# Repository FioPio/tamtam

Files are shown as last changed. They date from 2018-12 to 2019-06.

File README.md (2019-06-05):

# tamtam
!!!!!!!!!!!!!!!!!!!!!!!!!!!!!!!UNDER CONSTRUCTION!!!!!!!!!!!!!!!!!!!!!!!!!!!!!!
This repo holds Tamtam (an small low-cost humanoid).
It will contain all the documentation needed to build that litte
robot.
It has 19 DOF, those will be mg90s. I expect to finish it very
son. Since now I have done all of the hardware, the electronics are 
working fine and I've already computed the inverse kinematics.

I am working on the code,and there will be also a document explaining
all the details , since this is my degree project.

the robot is 223.25 mm hight

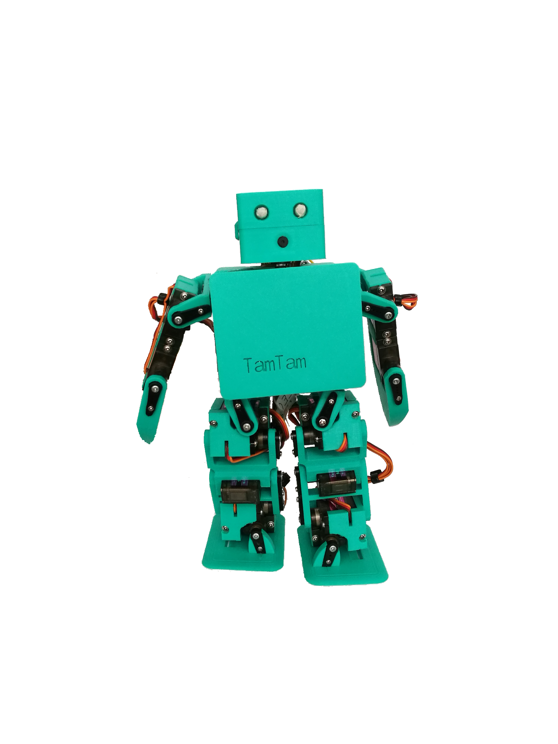
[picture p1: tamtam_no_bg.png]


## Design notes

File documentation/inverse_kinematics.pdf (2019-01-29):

INVERSE KINEMATICS:

That’s a Tamtam leg schema in the zy and zx planes :

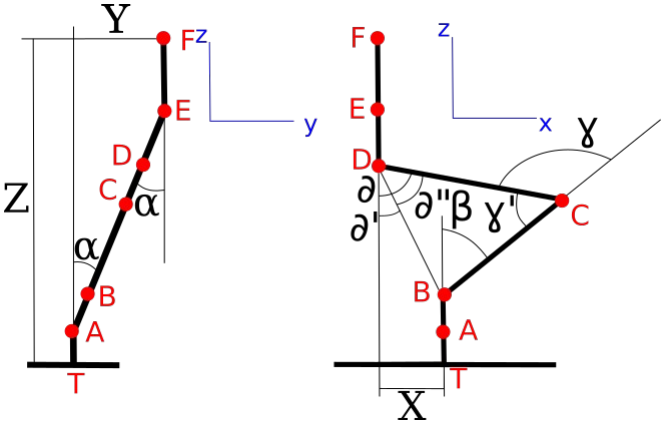
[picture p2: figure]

Where T is refered from F and has the components ( X , Y, Z ), so first we may compute the α angle:

α=tg⁻¹
(

Y
Z−TA−EF

)

Now we can compute the distance between B and D using pitagoras:

BD=√ X
2
+(Y −ABsinα−DE sinα)

2
+( Z− ABcosα−DE cosα−TA−EF )

2

So now we have a triangle which we know all the dimensions but the angles: aplying the law of cosinus we may obtain γ’ angle:

γ '=cos⁻¹
(

BC²

+CD²− BD²

### 2 BC CD

)

and since γ = 180 -γ’ :

γ=180−cos⁻¹
(

BC²

+CD²−BD²

### 2 BC CD

)

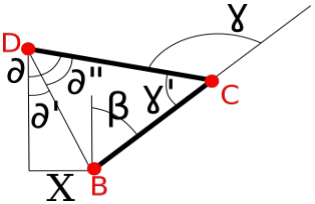
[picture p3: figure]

we also may compute ð’: δ '=sin⁻¹ (

X
BD

) and ð”: δ ''=cos⁻¹
(

CD²

+ BD²−BC²
2CD BD

)

And since ð = ð’ + ð “:

δ=sin⁻¹
(

X
BD

)+cos⁻¹
(

CD²

+ BD²− BC²
2CD BD

)

And to finish, using the fact that adding all the intern angles of a triangle you get 180 degrees:

β=180−δ−(180−γ)=γ−δ

Now we need to add the rotation component for the leg, I’ll use a rotation matrix in Z axis:

so we obtain: x,y,z,ε → X,Y,Z:

to do so:
X = x cos ε + y sin ε
Y = y cos ε – x sin ε
Z= z
where ε is the F rotation angle.

by FioPio (Ferriol Pey Comas)

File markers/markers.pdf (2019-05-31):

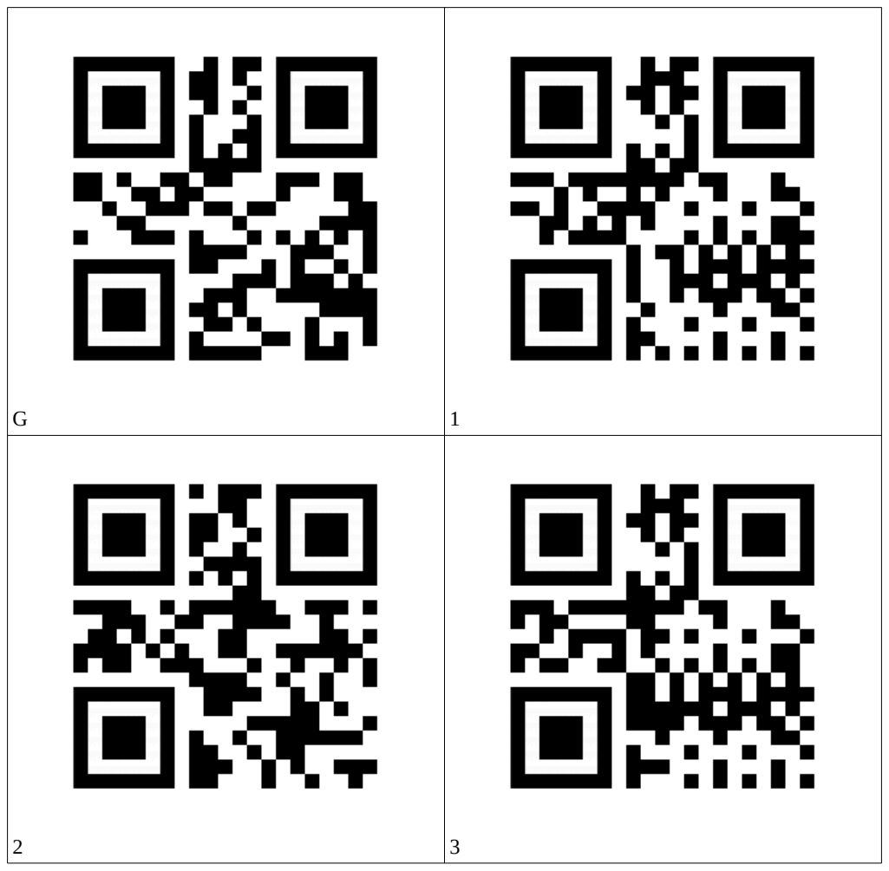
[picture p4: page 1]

G

1

2

3

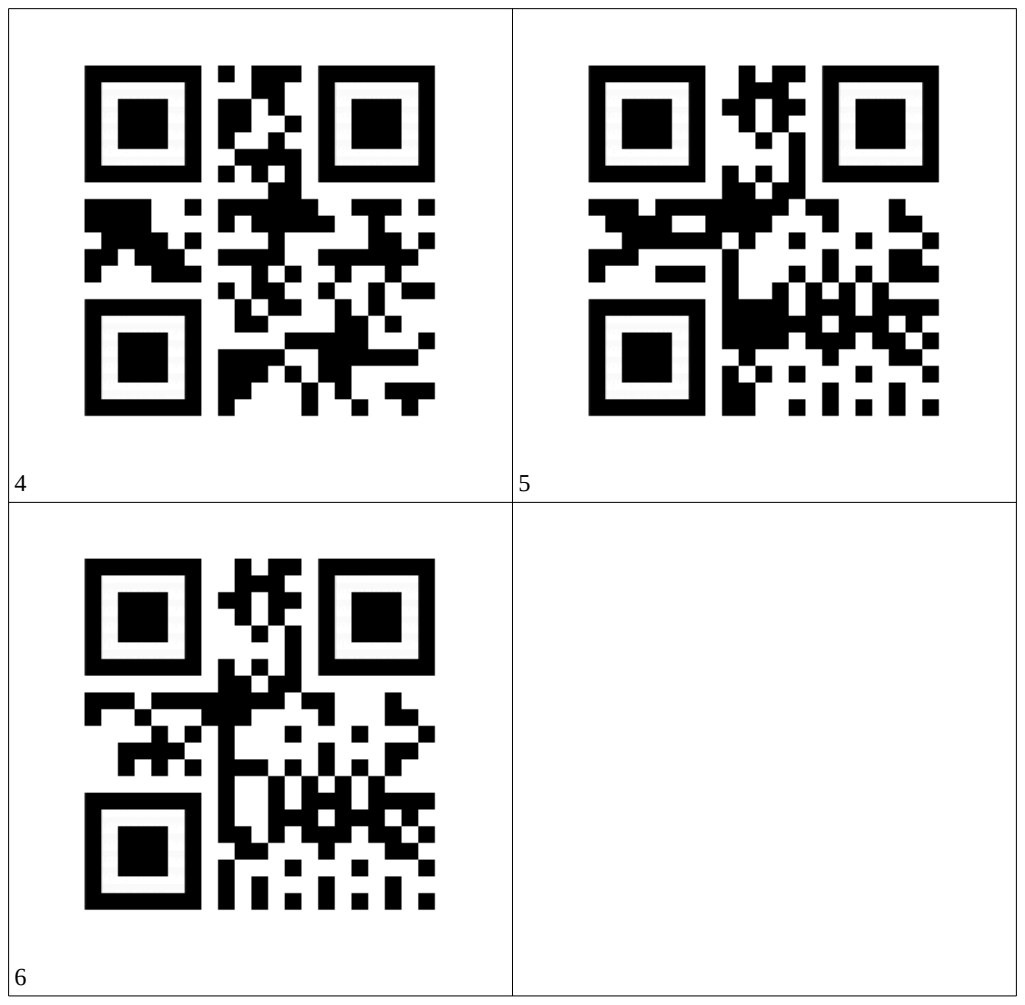
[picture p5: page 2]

4

5

6

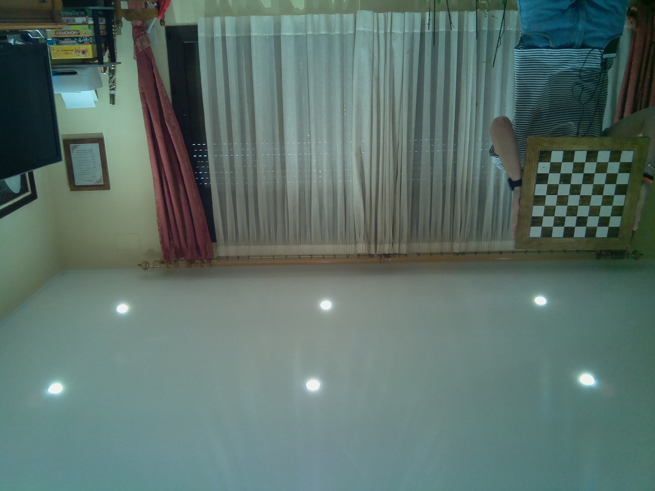
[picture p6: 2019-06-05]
code/rpi/photo_cal/photos/f18.jpg

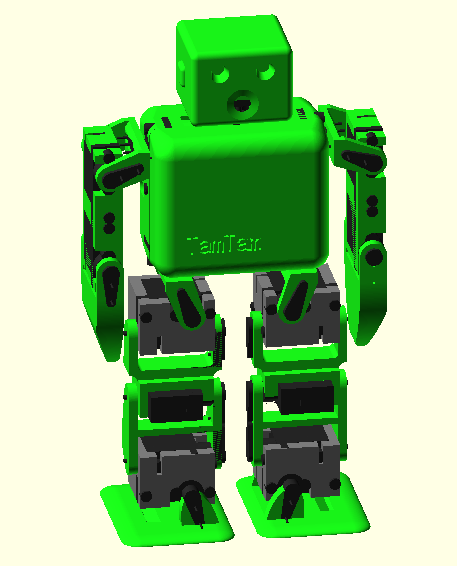
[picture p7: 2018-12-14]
TamTam_view1.png

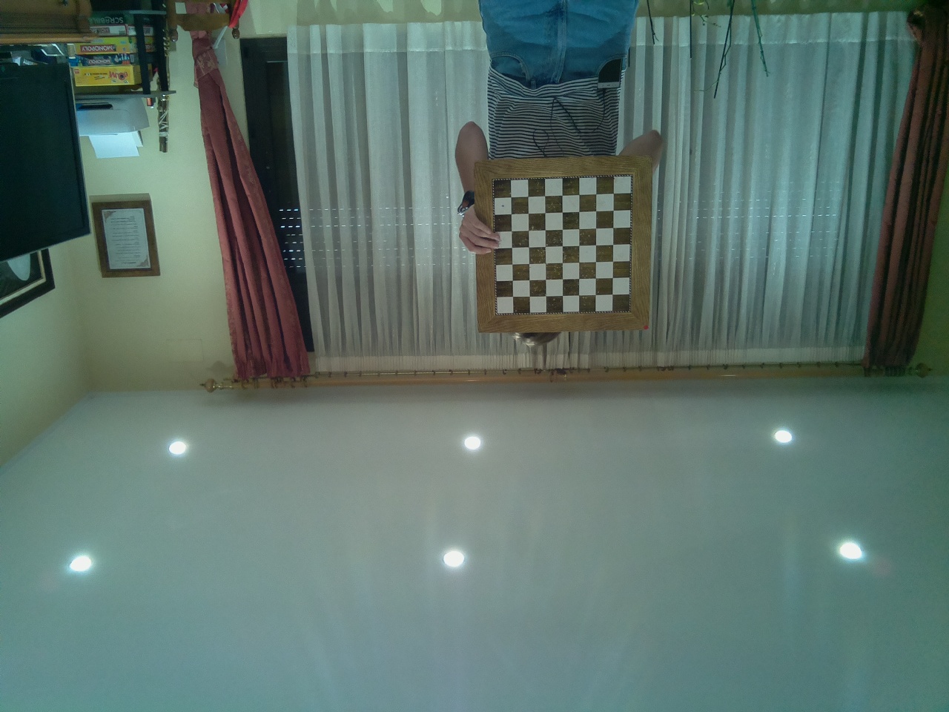
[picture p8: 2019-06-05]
code/rpi/photo_cal/photos/f10.jpg

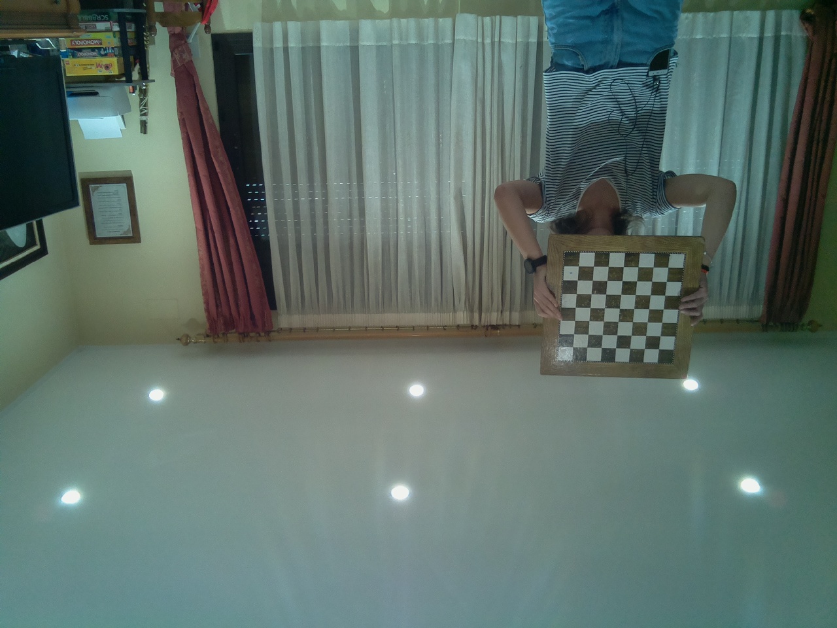
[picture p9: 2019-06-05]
code/rpi/photo_cal/photos/f13.jpg

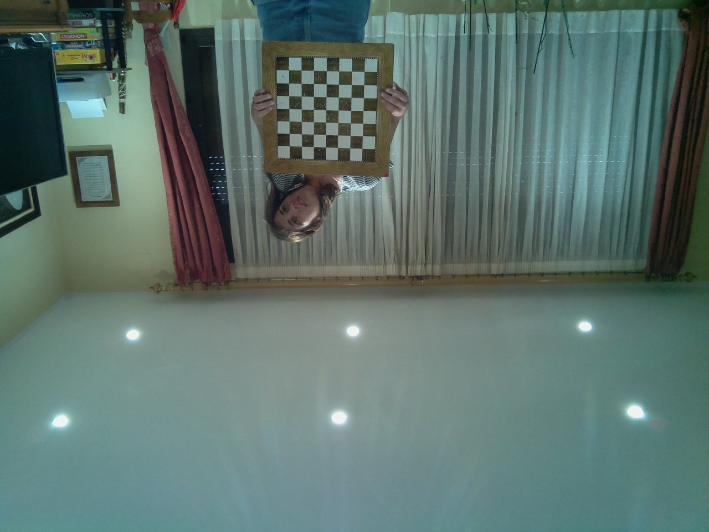
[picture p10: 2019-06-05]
code/rpi/photo_cal/photos/f7.jpg

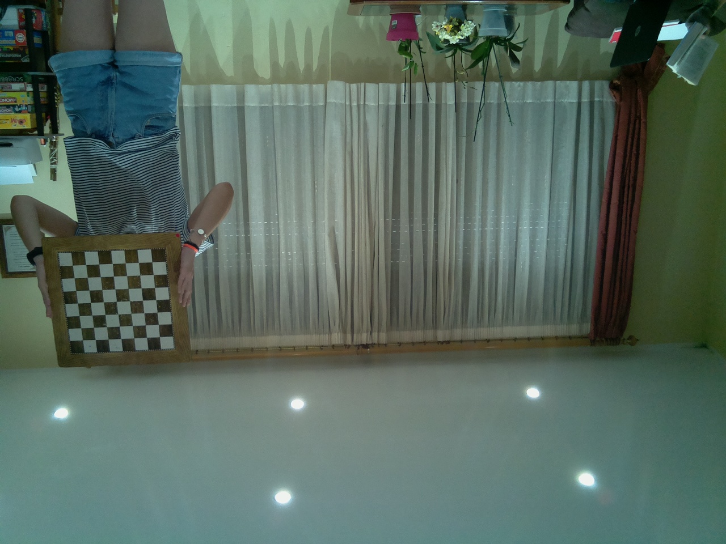
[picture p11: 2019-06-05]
code/rpi/photo_cal/photos/f2.jpg

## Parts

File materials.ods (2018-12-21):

component | units | aprox priece (€/u) | total priece | 3D piece | density (%) | p. time | units | total printing time | 12:25:00 | hours
MG90S | 19 | 1,822 | 34,618 | two_servo_holder | 10 | 01:00:00 | 2 | 03:50:00
Conic M2x6 | 14 | 0,0334 | 0,4676 | two_servo_holder (mirrored) | 10 | 01:00:00 | 2
ATMega328P-AU | 1 | 1,164 | 1,164 | right_foot | 10 | 01:35:00 | 1 | 02:40:00
SD20 | 1 | 11,5 | 11,5 | right_foot (mirrored) [for left foot] | 10 | 01:35:00 | 1
board | 1 | 0,858 | 0,858 | lower_leg_right | 10 | 00:45:00 | 1 | 01:15:00
100nF Capacitor | 1 | 0,00578 | 0,00578 | lower_leg_right (mirrored) [for left] | 10 | 00:45:00 | 1
47uF Capacitor | 1 |  | 0 | upper_leg_right | 10 | 00:56:00 | 1 | 01:15:00
22pF Capacitor | 2 | 0,007066666666667 | 0,014133333333333 | upper_leg_right (mirrored) [for left] | 10 | 00:56:00 | 1
IRF3205 | 1 | 0,238 | 0,238 | right_leg_bracket | 10 | 00:51:00 | 1 | 01:10:00
4k7 Resistor | 3 | 0,00526 | 0,01578 | right_leg_bracket (mirrored) [for left] | 10 | 00:51:00 | 1
10k Resistor | 3 | 0,0025 | 0,0075 | servo_body_holder | 10 | 02:15:00 | 1 | 02:15:00
1k Resistor | 1 | 0,0052 | 0,0052
2k Resistor | 1 | 0,0022 | 0,0022
Crystal HC-49 | 1 | 0,188 | 0,188
Lipo | 2
DC/DC | 1
switch | 1
RGB leds | 2
Extra
HC-06 | 1 | 2,73666666666667 | 2,73666666666667
Raspberry pi zero | 1 | 19 | 19
raspi mini cam | 1 | 8,87 | 8,87
i2c 5to3V converter | 1 | 0,3 | 0,3
 |  |  | 0
 |  |  | 0
 |  |  | 0
 |  | Basic cost: | 49,0841933333333
 |  | Basic + BT:

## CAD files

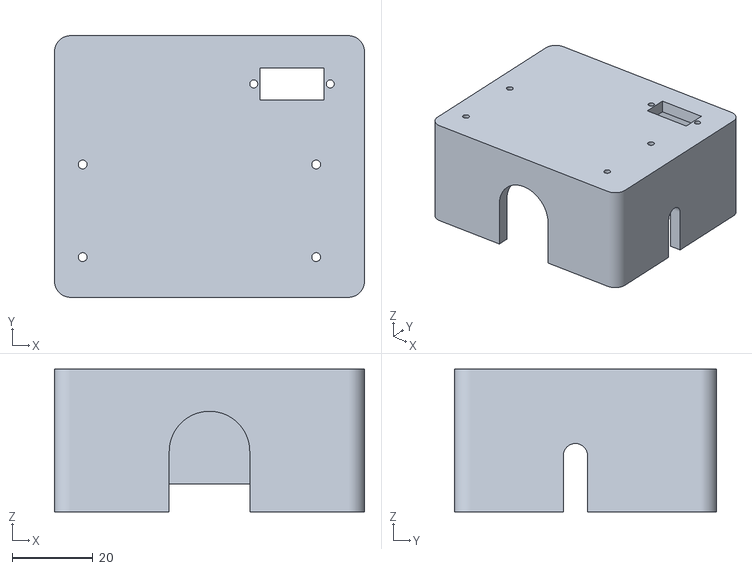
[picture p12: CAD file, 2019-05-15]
STL/body_back_cover.stl
77.0 x 65.0 x 35.5

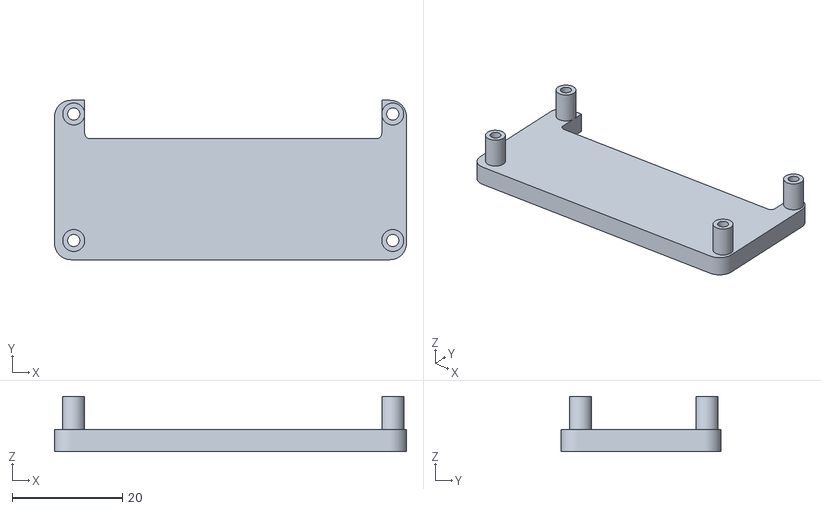
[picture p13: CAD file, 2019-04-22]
STL/rpi_protection.stl
64.0 x 29.0 x 10.0

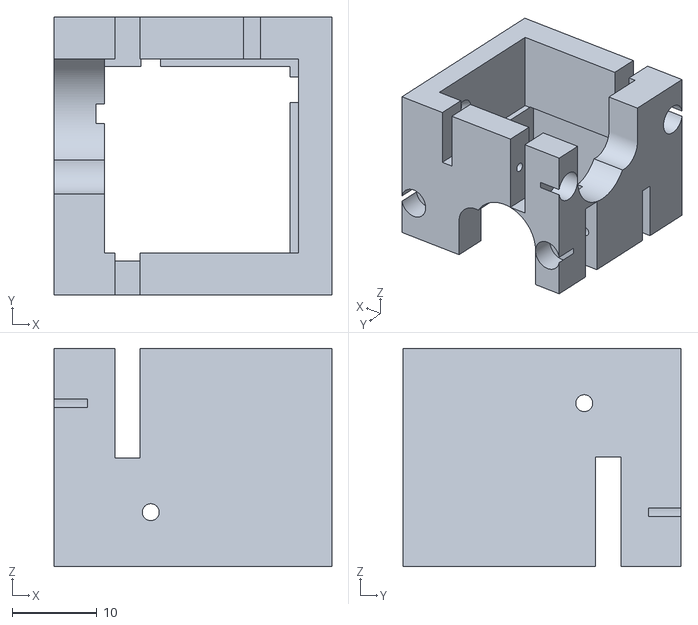
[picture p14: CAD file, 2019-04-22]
STL/two_servo_holder.stl
32.9 x 32.9 x 25.8

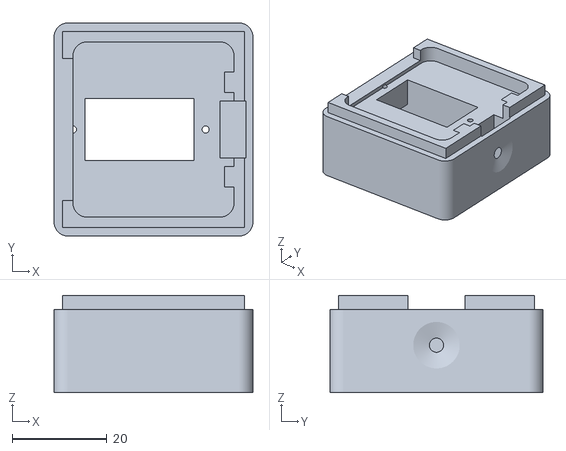
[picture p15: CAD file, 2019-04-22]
STL/head_lower_part.stl
42.0 x 45.0 x 20.5

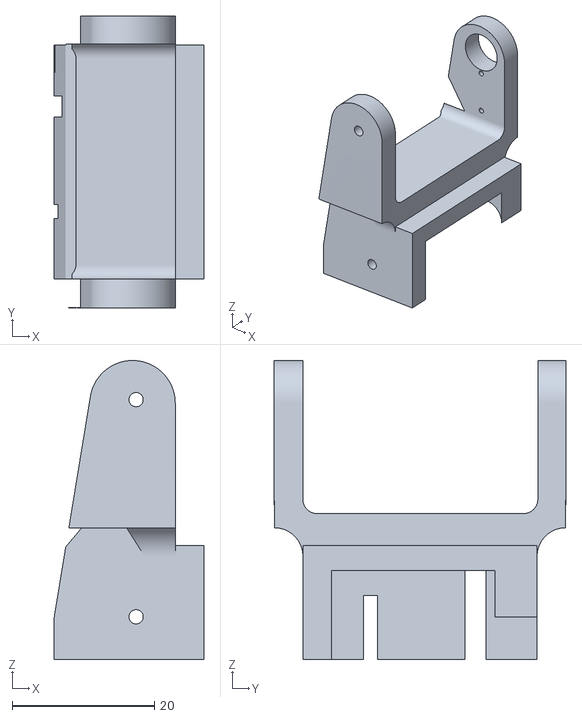
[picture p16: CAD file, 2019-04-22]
STL/upper_leg_right.stl
21.0 x 41.0 x 42.0

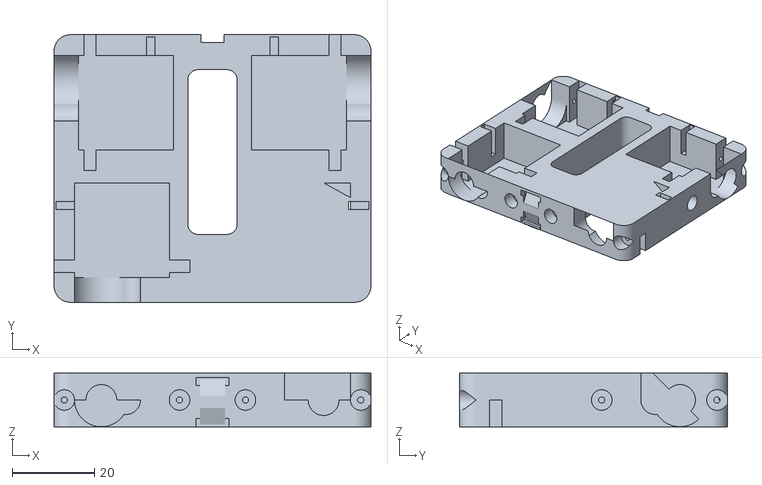
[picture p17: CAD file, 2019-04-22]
STL/servo_body_holder.stl
77.0 x 65.0 x 13.0

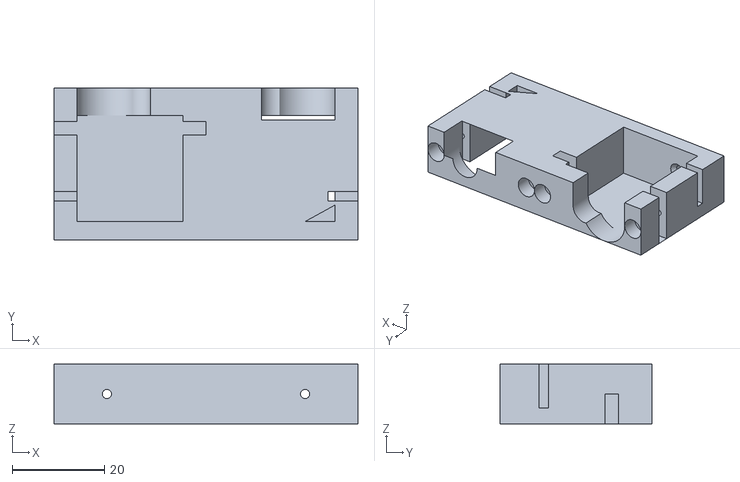
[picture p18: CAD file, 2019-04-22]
STL/arm_upper_part.stl
66.0 x 33.0 x 13.0

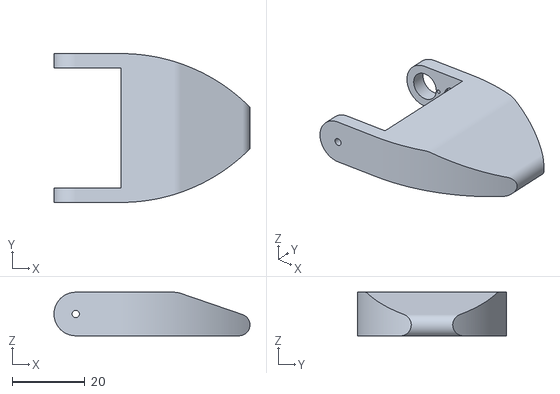
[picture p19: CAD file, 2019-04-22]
STL/arm_lower_part.stl
54.0 x 41.0 x 12.0

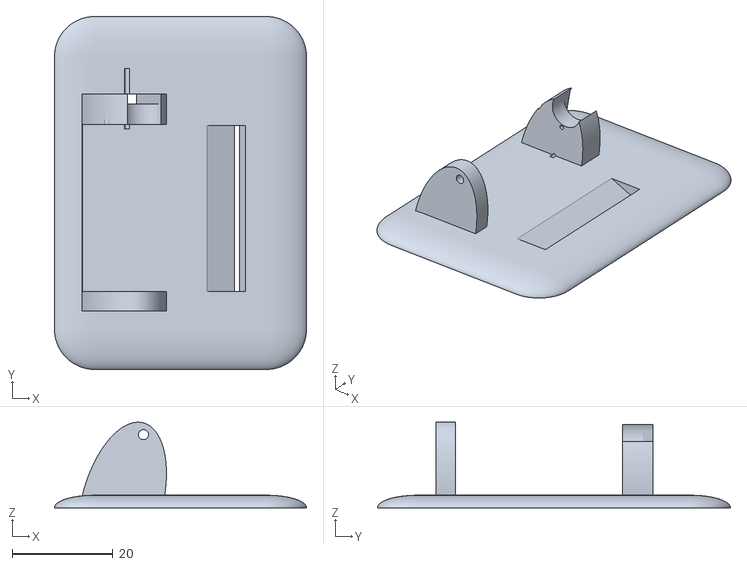
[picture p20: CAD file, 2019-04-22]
STL/right_foot.stl
50.0 x 70.0 x 17.0

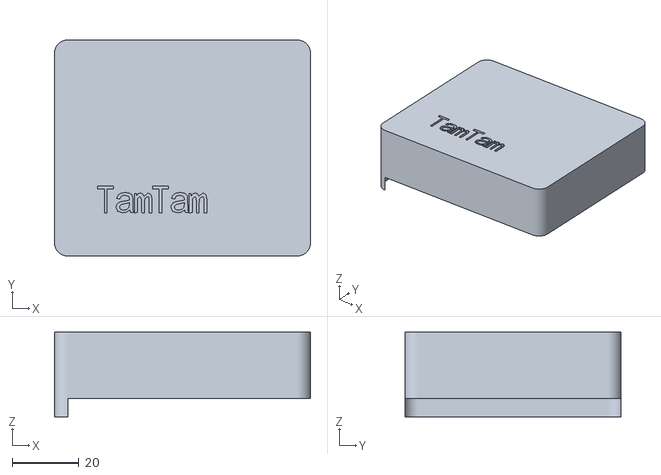
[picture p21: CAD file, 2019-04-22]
STL/body_front_cover.stl
77.0 x 65.0 x 25.5

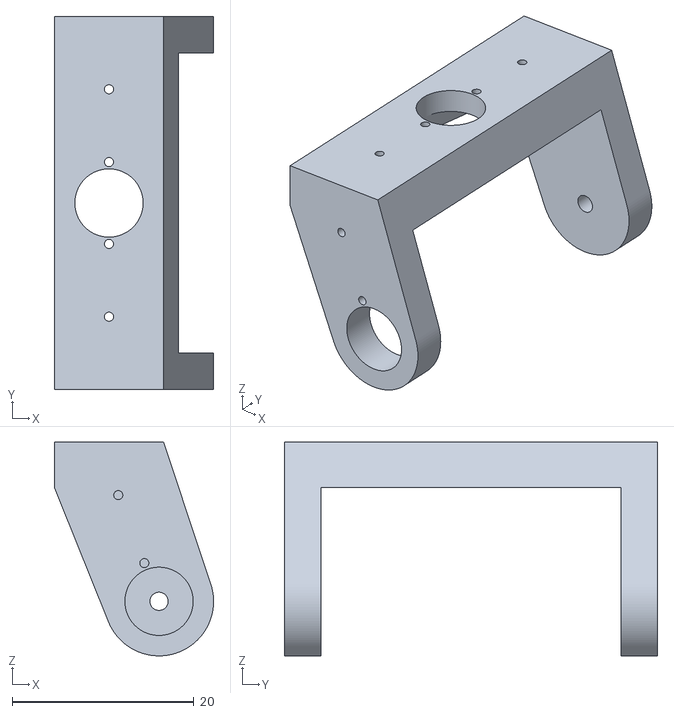
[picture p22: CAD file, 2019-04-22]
STL/right_leg_bracket.stl
17.5 x 41.0 x 23.5

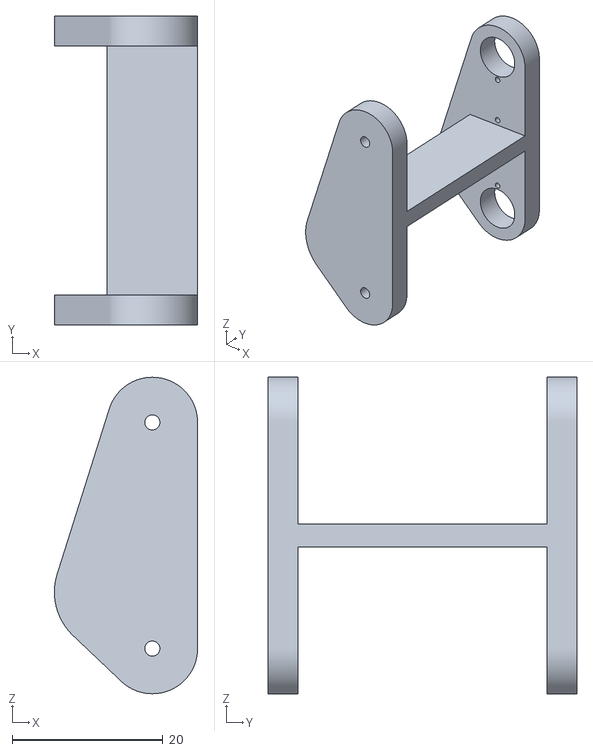
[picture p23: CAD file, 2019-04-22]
STL/lower_leg_right.stl
19.0 x 41.0 x 42.0

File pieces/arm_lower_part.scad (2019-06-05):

/***************************************************************
 *                          arm_lower_part                      
 ***************************************************************
 * @author  FioPio (Ferriol Pey Comas)   ferriol73pey@gmail.com  
 * @version v1.0       14/12/2018                                
 ***************************************************************
 * This file contains the 3D model of the lower part of the arm.
 **************************************************************/
use<mg90s.scad>
$fn=500;

R=50;
difference()
{
   intersection()
   {
      hull()
      {
         rotate([-90,0])cylinder(r=6,h=41);
         translate([45-6-12,0,0])rotate([-90,0])cylinder(r=6,h=41);
         translate([45,0,-3])rotate([-90,0])cylinder(r=3,h=41);
      }
      union()
      {
         intersection()
         {
            translate([12.5,41-R,-10])cylinder(r=R,h=20);
            translate([12.5,R,-10])cylinder(r=R,h=20);
					    }
					    translate([-6,0,-10])cube([18.5,41,20]);
      }
   }
   translate([-8,4,-10])cube([12.5+8,33,20]);
   translate([0,8])rotate([-90,180])mg90s(180,false,true);
}

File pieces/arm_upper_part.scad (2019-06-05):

/****************************************************************
 *                          arm_upper_part                       
 ****************************************************************
 * @author  FioPio  (Ferriol Pey Comas)   ferriol73pey@gmail.com 
 * @version v1.0       14/12/2018                                
 ****************************************************************
 * This file contains the 3D model of the upper part of the arm. 
 ***************************************************************/
 
use <mg90s.scad>
$fn=120;

difference()
{
   translate([-10,-4,0])cube([66,33,13]);
   translate([1.5,0,6.5])rotate([-90,0])
   {
			   mg90s(-1,false,true);
      translate([-13,-9,4.5])cube([10,12,2]);  
		 }
   translate([46-1.5,0,6.5])rotate([-90,180])
   {
			   mg90s(-1,false,true);
			   translate([-15,-3,4.5])cube([10,10,2]);  
			}
   translate([-5,22,6.5])cube([16,8,10]);
   translate([44-9,22,6.5])cube([16,8,10]);
}

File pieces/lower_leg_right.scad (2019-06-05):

/*************************************************************
 *                            lower_leg                       
 *************************************************************
 * @author FioPio (Ferriol Pey Comas)  ferriol73pey@gmail.com 
 * @version v1.1    04/12/2018                                
 *************************************************************
 * This file contains the lower part of the leg.              
 ************************************************************/
 
use <mg90s.scad>
$fn=120;
R=6;

difference()
{
   hull()
   {
      rotate([-90,0])cylinder(r=R,h=33+8);
      translate([0,0,30])rotate([-90,0])cylinder(r=R,h=33+8); 
      translate([-5,0,7.5])rotate([-90,0])cylinder(r=8,h=33+8); 
   }
   translate([-36,4,-10])cube([30,33,60]);
   translate([-7,4,-10])cube([30,33,23.5]);
   translate([-7,4,16.5])cube([30,33,22]);
   translate([0,8])rotate([-90,180])mg90s(90,false,true);
   translate([0,8,30])rotate([-90,0])mg90s(90,true,true);
}

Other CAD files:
pieces/write/Letters.dxf
pieces/right_leg_bracket.scad
pieces/body_back_cover.scad
pieces/body_data.scad
pieces/body_front_cover.scad
pieces/head_lower_part.scad
pieces/head_upper_part.scad
pieces/mg90s.scad
pieces/right_foot.scad
pieces/rpi_protection.scad
pieces/servo_body_holder.scad
pieces/two_servo_holder.scad
pieces/upper_leg_right.scad
pieces/write/write.scad

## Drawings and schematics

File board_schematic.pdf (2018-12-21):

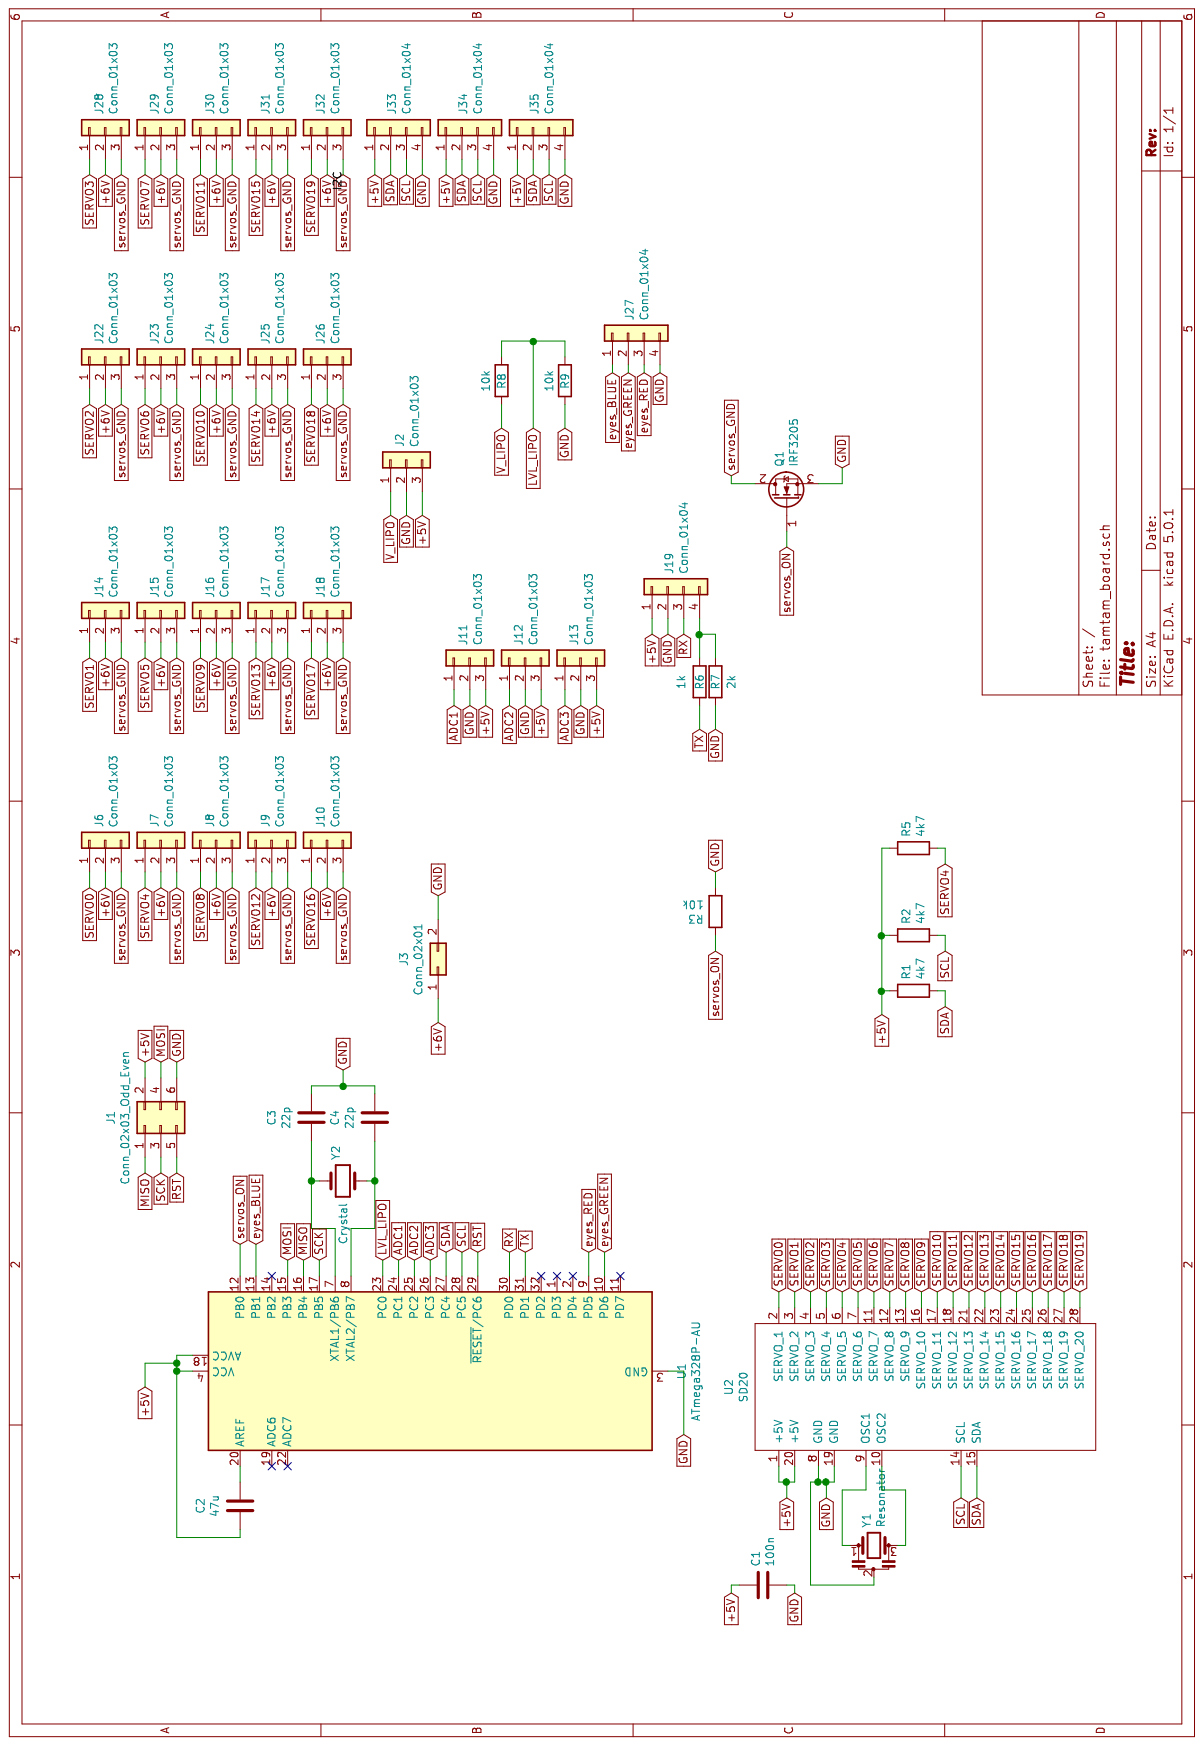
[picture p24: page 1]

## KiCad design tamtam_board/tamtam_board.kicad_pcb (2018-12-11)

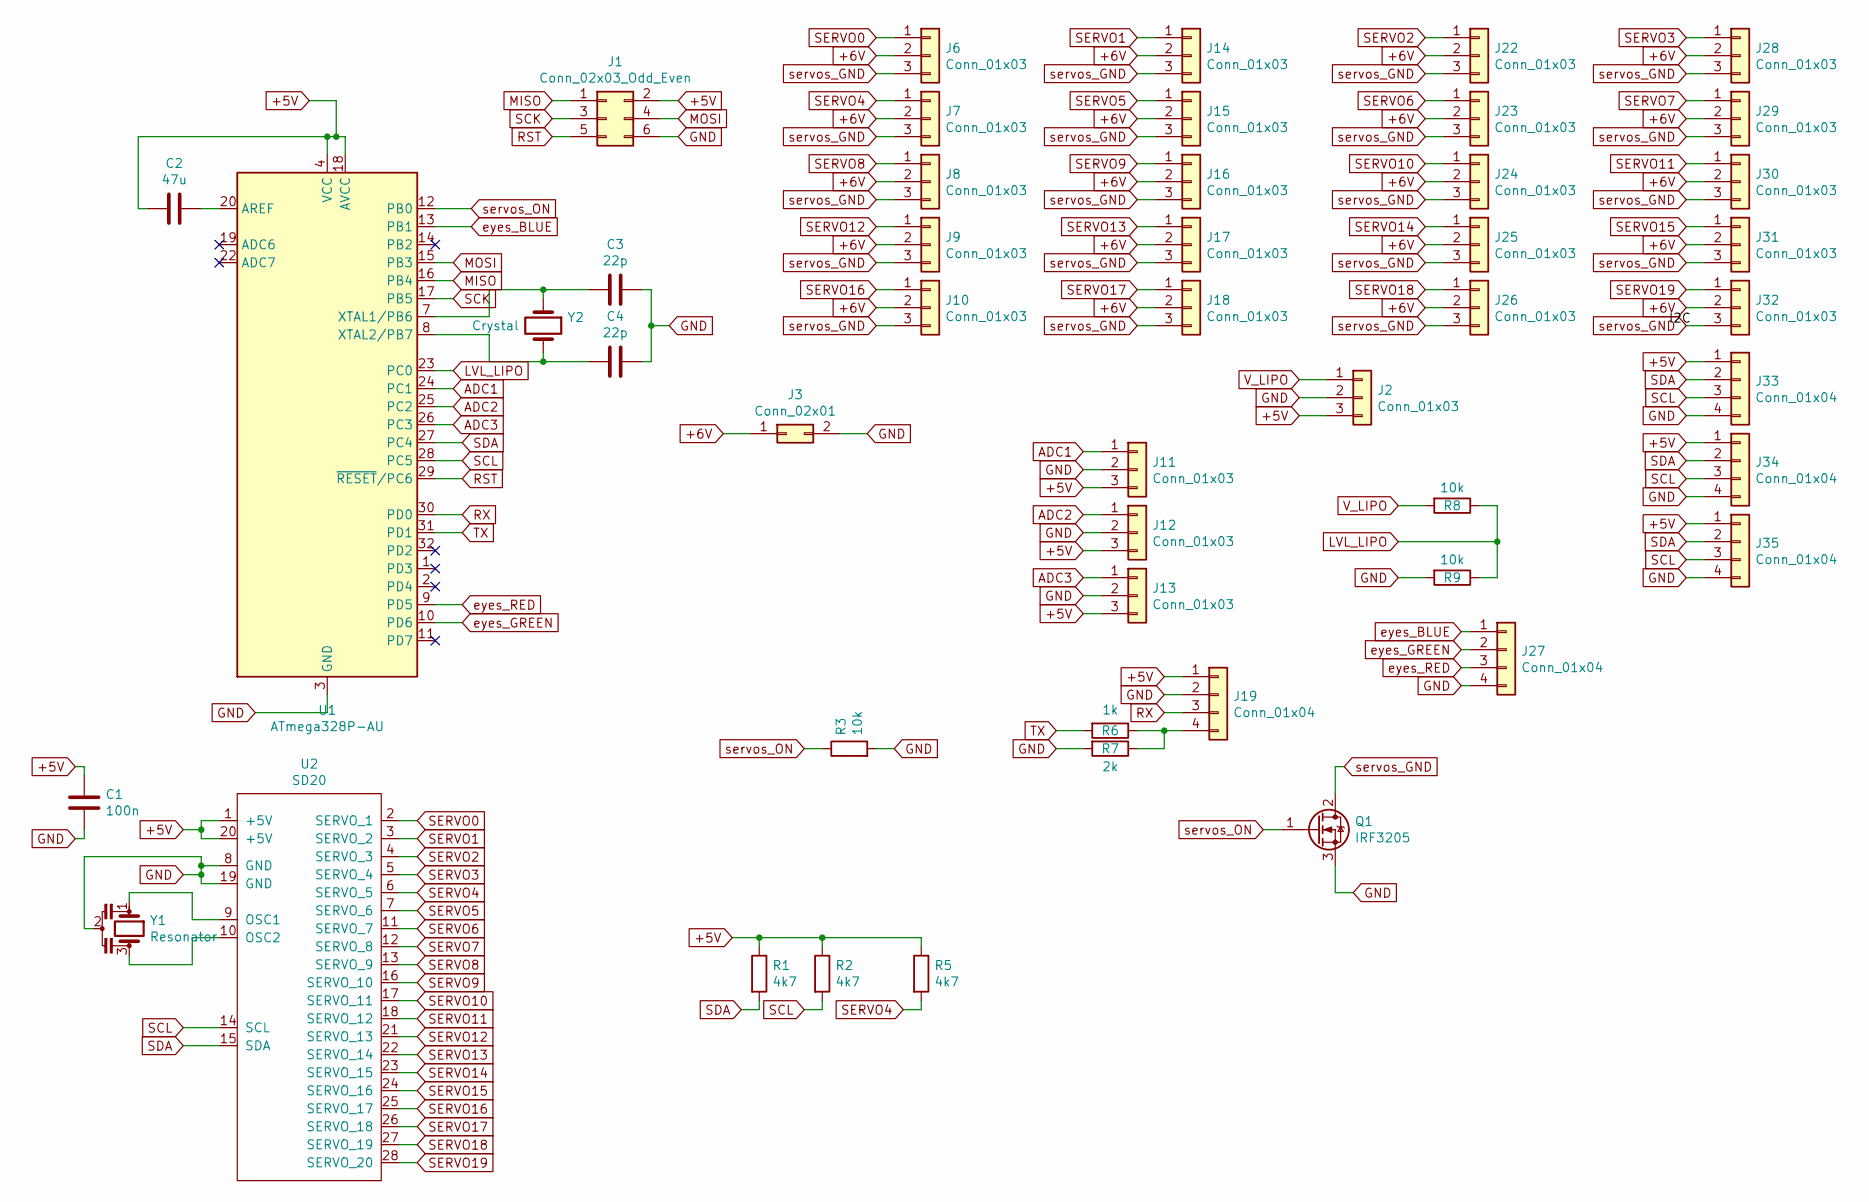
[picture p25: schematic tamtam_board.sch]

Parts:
C1: 100n; C_0603_1608Metric_Pad1.05x0.95mm_HandSolder
C2: 47u; C_0603_1608Metric_Pad1.05x0.95mm_HandSolder
C3, C4: 22p; C_0603_1608Metric_Pad1.05x0.95mm_HandSolder
J1: Conn_02x03_Odd_Even; PinHeader_2x03_P2.54mm_Vertical
J2, J6, J7, J8, J9, J10, J11, J12, J13, J14, J15, J16, J17, J18, J22, J23, J24, J25, J26, J28, J29, J30, J31, J32: Conn_01x03; PinHeader_1x03_P2.54mm_Vertical
J3: Conn_02x01; PinHeader_2x01_P2.54mm_Vertical
J19, J27, J33, J34, J35: Conn_01x04; PinHeader_1x04_P2.54mm_Vertical
Q1: IRF3205; TO-220-3_Vertical
R1, R2, R5: 4k7; R_0603_1608Metric_Pad1.05x0.95mm_HandSolder
R3, R8, R9: 10k; R_0603_1608Metric_Pad1.05x0.95mm_HandSolder
R6: 1k; R_0603_1608Metric_Pad1.05x0.95mm_HandSolder
R7: 2k; R_0603_1608Metric_Pad1.05x0.95mm_HandSolder
U1: ATmega328P-AU; TQFP-32_7x7mm_P0.8mm
U2: SD20; DIP-28_W7.62mm_Socket_LongPads
Y1: Resonator; Resonator-3Pin_W7.0mm_H2.5mm
Y2: Crystal; Crystal_HC49-4H_Vertical

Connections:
+5V: C1.1, C2.2, J1.2, J2.3, J11.3, J12.3, J13.3, J19.1, J33.1, J34.1, J35.1, R1.1, R2.1, R5.1, U1.4 (VCC), U1.6 (VCC), U1.18 (AVCC), U2.1 (+5V), U2.20 (+5V)
+6V: J3.1, J6.2, J7.2, J8.2, J9.2, J10.2, J14.2, J15.2, J16.2, J17.2, J18.2, J22.2, J23.2, J24.2, J25.2, J26.2, J28.2, J29.2, J30.2, J31.2, J32.2
ADC1: J11.1, U1.24 (PC1)
ADC2: J12.1, U1.25 (PC2)
ADC3: J13.1, U1.26 (PC3)
GND: C1.2, C3.1, C4.1, J1.6, J2.2, J3.2, J11.2, J12.2, J13.2, J19.2, J27.4, J33.4, J34.4, J35.4, Q1.3 (S), R3.2, R7.2, R9.2, U1.3 (GND), U1.5 (GND), U1.21 (GND), U2.8 (GND), U2.19 (GND), Y1.2
LVL_LIPO: R8.1, R9.1, U1.23 (PC0)
MISO: J1.1, U1.16 (PB4)
MOSI: J1.4, U1.15 (PB3)
unnamed: C2.1, U1.20 (AREF)
unnamed: C3.2, U1.7 (XTAL1/PB6), Y2.1
unnamed: C4.2, U1.8 (XTAL2/PB7), Y2.2
unnamed: J19.4, R6.1, R7.1
unnamed: U2.9 (OSC1), Y1.1
unnamed: U2.10 (OSC2), Y1.3
RST: J1.5, U1.29 (~RESET~/PC6)
RX: J19.3, U1.30 (PD0)
SCK: J1.3, U1.17 (PB5)
SCL: J33.3, J34.3, J35.3, R2.2, U1.28 (PC5), U2.14 (SCL)
SDA: J33.2, J34.2, J35.2, R1.2, U1.27 (PC4), U2.15 (SDA)
SERVO0: J6.1, U2.2 (SERVO_1)
SERVO1: J14.1, U2.3 (SERVO_2)
SERVO2: J22.1, U2.4 (SERVO_3)
SERVO3: J28.1, U2.5 (SERVO_4)
SERVO4: J7.1, R5.2, U2.6 (SERVO_5)
SERVO5: J15.1, U2.7 (SERVO_6)
SERVO6: J23.1, U2.11 (SERVO_7)
SERVO7: J29.1, U2.12 (SERVO_8)
SERVO8: J8.1, U2.13 (SERVO_9)
SERVO9: J16.1, U2.16 (SERVO_10)
SERVO10: J24.1, U2.17 (SERVO_11)
SERVO11: J30.1, U2.18 (SERVO_12)
SERVO12: J9.1, U2.21 (SERVO_13)
SERVO13: J17.1, U2.22 (SERVO_14)
SERVO14: J25.1, U2.23 (SERVO_15)
SERVO15: J31.1, U2.24 (SERVO_16)
SERVO16: J10.1, U2.25 (SERVO_17)
SERVO17: J18.1, U2.26 (SERVO_18)
SERVO18: J26.1, U2.27 (SERVO_19)
SERVO19: J32.1, U2.28 (SERVO_20)
TX: R6.2, U1.31 (PD1)
V_LIPO: J2.1, R8.2
eyes_BLUE: J27.1, U1.13 (PB1)
eyes_GREEN: J27.2, U1.10 (PD6)
eyes_RED: J27.3, U1.9 (PD5)
servos_GND: J6.3, J7.3, J8.3, J9.3, J10.3, J14.3, J15.3, J16.3, J17.3, J18.3, J22.3, J23.3, J24.3, J25.3, J26.3, J28.3, J29.3, J30.3, J31.3, J32.3, Q1.2 (D)
servos_ON: Q1.1 (G), R3.1, U1.12 (PB0)

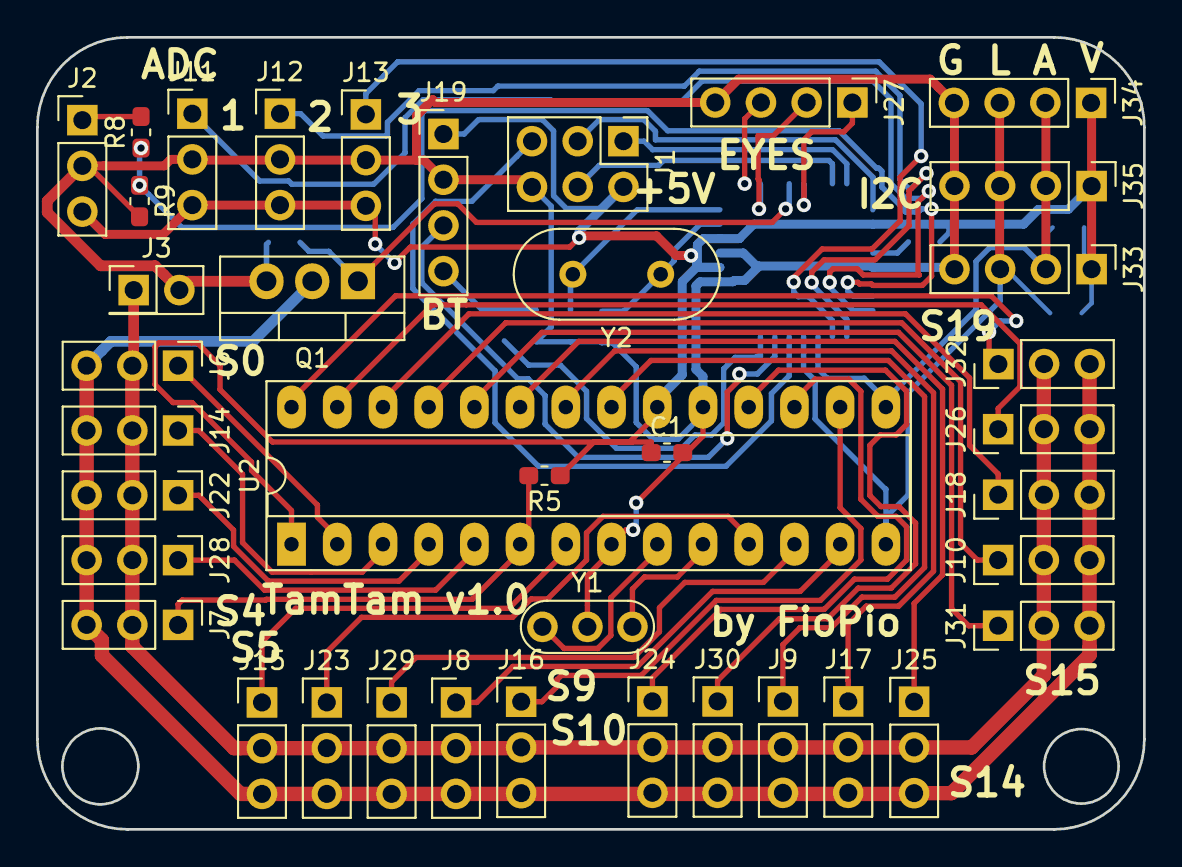
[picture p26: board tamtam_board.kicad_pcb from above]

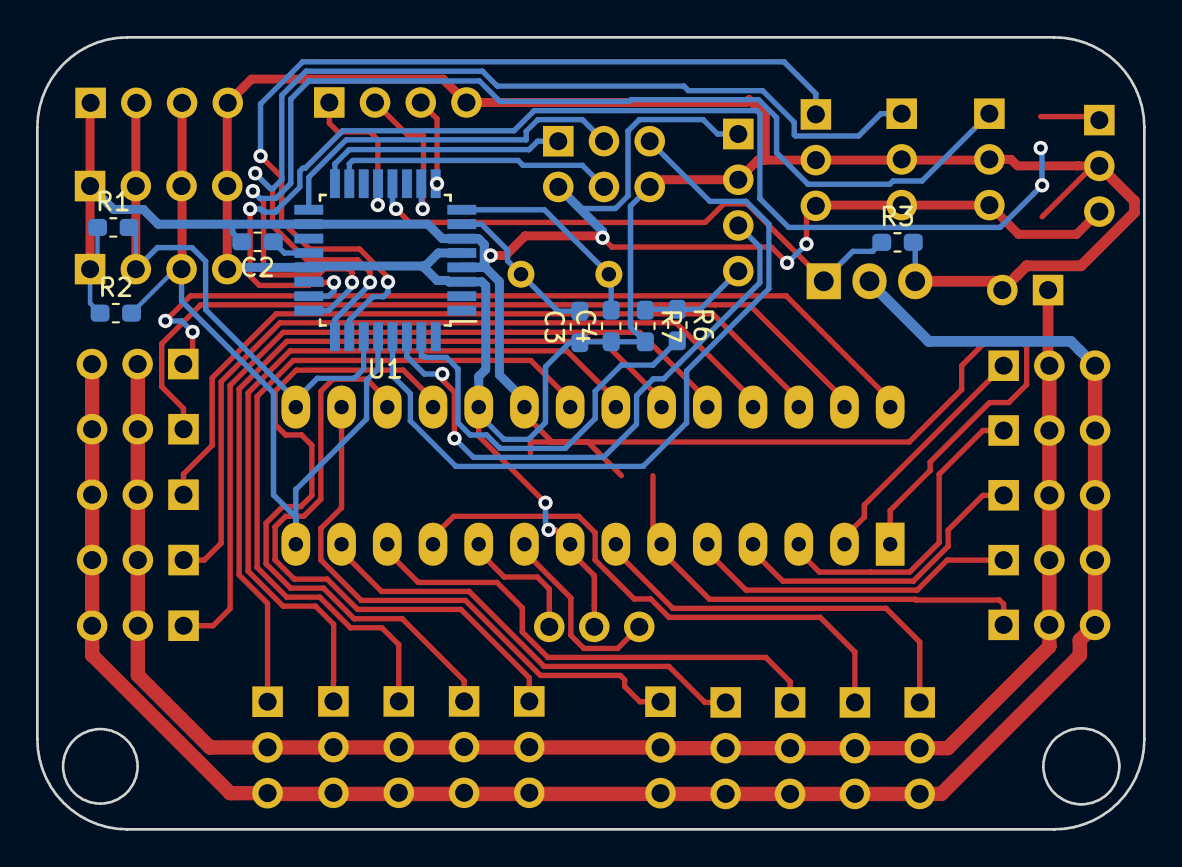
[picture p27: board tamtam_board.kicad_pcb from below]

Board: 2 copper layers, 61.5 x 44.0 mm, 48 parts (9 on the bottom side), 47 nets.

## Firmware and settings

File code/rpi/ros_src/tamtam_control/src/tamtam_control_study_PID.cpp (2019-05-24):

#include <tamtam.h>
#include <ros/ros.h>
#include <orientation/Orientation.h>
#include <fstream>
#include <stdio.h>
#include <math.h>

#define T_SAMPLE                     25000
#define FILENAME "/home/pi/data/data.txt"

//Walking and base parameters
#define T_WALKING                       2.0
#define STAND_HEIGH                   121.0
#define BASE_HEIGH                    107.5
#define STEP_HEIGH                     15
#define STEP_LATERAL                   35
#define STEP_FORWARD                   22.5
#define W              (2.0*PI)/T_WALKING

//PID
#define PID_SAMPLE_TIME                50 //ms
#define SP_X                            0.0
#define SP_Y                            0.0

#define KP_a                            0.0
#define KP_b                            0.0
#define KP_d                            0.0
#define KP_e                            0.0

#define KI_a                            0.0
#define KI_b                            0.0
#define KI_d                            0.0
#define KI_e                            0.0

#define KD_a                            0.0
#define KD_b                            0.0
#define KD_d                            0.0
#define KD_e                            0.0

#define MAX_EPSILON_CORRECTION         20.0
#define MAX_DELTA_CORRECTION           20.0
#define MAX_BETA_CORRECTION            20.0
#define MAX_ALPHA_CORRECTION           20.0

class TamTam_Control
{
public:
  TamTam_Control()
  {
    Tam.setup();
    readed=false;
    write=true;
    myfile.open (FILENAME);
    this->n = ros::NodeHandle("~");
    this->orient_sub = n.subscribe("/orientation",1, &TamTam_Control::orientation_callback, this);
    t_ant=millis();
    t_init_file=t_ant;
    step=255;
    Tam.to_home();
    left_leg.zeta=0;
    right_leg.zeta=0;
    left_leg.x=0;
    right_leg.x=0;
    left_leg.y=0;
    right_leg.y=0;
    left_leg.z=121;
    right_leg.z=121;
    correction_epsilon=0;
    correction_delta=0;
    correction_beta=0;
    correction_alpha=0;
    correction_left=false;
    correction_right=false;
  }
  
  void orientation_callback(const orientation::Orientation orient_msg)
  {
    yaw=orient_msg.yaw;
    roll=orient_msg.roll;
    pitch=orient_msg.pitch;
    readed=true;
  }
  
  ////////////////////////////////////////////////////////////
  void loop()
  {
    switch(step)
    {
      case 255:
	    if(t>T_WALKING)
	    {
	      t=0;
	      myfile << "end waiting step-1\n";
	      Tam.set_eyes_colour(BLUE);
	      step=0;
	    }
	    break;
	
      case 0:  //get the base position
	    left_leg.z=STAND_HEIGH - (STAND_HEIGH-BASE_HEIGH)*sin(W*t);
	    right_leg.z=STAND_HEIGH - (STAND_HEIGH-BASE_HEIGH)*sin(W*t);
	    if(t>T_WALKING/4.0)
	    {
	      left_leg.z=BASE_HEIGH;
	      right_leg.z=BASE_HEIGH;
	      t=0;
	      step++;
	    }
	    break;
	    
      case  1: //put the robot on the right foot
	    right_leg.y=STEP_LATERAL * sin(W*t);
	    left_leg.y= STEP_LATERAL * sin(W*t);
	    if(t > T_WALKING/4.0 )
	    {
	      t  = 0;
	      right_leg.y = STEP_LATERAL ;
	      left_leg.y = STEP_LATERAL ;
	      step++;
	      correction_epsilon_r=15;
	      correction_right=true;
	    }
	    break;

      case  2: //put the foot up
	    left_leg.z= BASE_HEIGH-STEP_HEIGH * sin(W*t);
	    if(t > T_WALKING/4.0 )
	    {
	      t  = 0;
	      left_leg.z = BASE_HEIGH-STEP_HEIGH ;
	      step++;
	      Tam.set_eyes_colour(RED);
	    }
	    break;
    }
    
    if((millis()-t_init_file)>T_SAMPLE && write)
    {
      write=false;
      myfile.close();
      ROS_INFO("DADES ESCRITES");
      delay(30);
      Tam.set_eyes_colour(OFF);
      delay(20);
      Tam.disable_motors();
      delay(5);
    }
    else
    {
      if(write && readed)
      {
	    readed=false;
	    myfile << pitch << " ; "<<yaw<<" ; "<<roll<<" ; "<<millis()-t_init_file<<"\n";
      }
    }
    if(write)
    {
	  //computig the angles to get the desired position
      left_cfg=Tam.compute_angles(left_leg);
      right_cfg=Tam.compute_angles(right_leg);
      //aplaying the corrections for the PID stabilizing

      if( correction_left || correction_right) compute_corrections();
      if(correction_left)
      {
		left_cfg.epsilon+=correction_epsilon;
		left_cfg.delta+=correction_delta;
		left_cfg.beta+=correction_beta;
		left_cfg.alpha+=correction_alpha;
	  }
	  if(correction_right)
	  {
		right_cfg.epsilon+=correction_epsilon;
		right_cfg.delta+=correction_delta;
		right_cfg.beta+=correction_beta;  
		right_cfg.alpha+=correction_alpha;
	  }
      //Seting the servomotors
      Tam.set_legs(right_cfg,left_cfg);
      delay(50);
      t+=(millis()-t_ant)/1000.0;
    }
  }
  //////////////////////////////////////////////////////////////////////  

private:
  float yaw, roll, pitch;
  ros::NodeHandle n;
  ros::Subscriber orient_sub;
  tamtam Tam;
  bool readed,write;
  std::ofstream myfile;
  unsigned int t_ant, t_init_file, t_ant_PID;
  char step;
  LEG_SETPOINT_T left_leg,right_leg;
  LEG_CONFIGURATION_T left_cfg, right_cfg;
  float t;
  float correction_epsilon, correction_delta, correction_beta, correction_alpha;
  float err_x, err_y, err_ant_x, err_ant_y, err_acu_x, err_acu_y, dt, dex, dey;
  bool correction_left, correction_right;
  void compute_corrections()
  {
	  dt=millis()-t_ant_PID;
	  if( dt > PID_SAMPLE_TIME )
	  {
		  t_ant_PID=millis();
		  dt/=1000.0;
		  err_x=SP_X-roll;
		  err_y=SP_Y-pitch;
		  err_acu_x+=err_x*dt;
		  err_acu_y+=err_y*dt;
		  dex = err_x - err_ant_x;
		  dey = err_y - err_ant_y;
		  err_ant_x=err_x;
		  err_ant_y=err_y;
		  correction_epsilon = KP_e * err_x + KD_e * (dex/dt) + KI_e * err_acu_x;
		  correction_alpha = KP_a * err_x + KD_a * (dex/dt) + KI_a * err_acu_x ;
		  correction_delta = KP_d * err_y + KD_d * (dey/dt) + KI_d * err_acu_y ;
		  correction_beta = KP_b * err_y + KD_b * (dey/dt) + KI_b * err_acu_y ;
		  
		  if(correction_epsilon > MAX_EPSILON_CORRECTION)
		  {
			  correction_epsilon = MAX_EPSILON_CORRECTION;
			  err_acu_x-=err_x*dt;
		  }
		  if(correction_epsilon < -MAX_EPSILON_CORRECTION)
		  {
			  correction_epsilon = -MAX_EPSILON_CORRECTION;
			  err_acu_x-=err_x*dt;
		  }
		  if(correction_delta > MAX_DELTA_CORRECTION)
		  {
			  correction_delta = MAX_DELTA_CORRECTION;
			  err_acu_y-=err_y*dt;
		  }
		  if(correction_delta < -MAX_DELTA_CORRECTION)
		  {
			  correction_delta = -MAX_DELTA_CORRECTION;
			  err_acu_y-=err_y*dt;
		  }
		  if(correction_beta > MAX_BETA_CORRECTION)
		  {
			  correction_beta = MAX_BETA_CORRECTION;
			  err_acu_y-=err_y*dt;
		  }
		  if(correction_beta < -MAX_BETA_CORRECTION)
		  {
			  correction_beta = -MAX_BETA_CORRECTION;
			  err_acu_y-=err_y*dt;
		  }
		  if(correction_alpha > MAX_ALPHA_CORRECTION)
		  {
			  correction_alpha = MAX_ALPHA_CORRECTION;
			  err_acu_x-=err_x*dt;
		  }
		  if(correction_epsilon < -MAX_ALPHA_CORRECTION)
		  {
			  correction_alpha = -MAX_ALPHA_CORRECTION;
			  err_acu_x-=err_x*dt;
		  }
	  }
  }
};


int main(int argc, char **argv)
{
  ros::init(argc, argv, "tamtam_control");
 TamTam_Control ttc;
  ROS_INFO("node starts");
  while (ros::ok())
    {
      ttc.loop();
      ros::spinOnce();
    }
  return 0;
}

/*#include <stdio.h>
#include <math.h>

#define T_WALKING                       2
#define STAND_HEIGH                   121.0
#define BASE_HEIGH                    107.5
#define STEP_HEIGH                     15
#define STEP_LATERAL                   35
#define STEP_FORWARD                   22.5
#define W              (2.0*PI)/T_WALKING



int main()
{
  tamtam Tam;
  
  left_leg.zeta=0;
  right_leg.zeta=0;
  left_leg.x=0;
  right_leg.x=0;
  left_leg.y=0;
  right_leg.y=0;   
  Tam.setup();
  Tam.to_home();
  long int t0=millis();
  float t=0;
  while(t < T_WALKING)
  {
    left_leg.z=STAND_HEIGH - (STAND_HEIGH-BASE_HEIGH)*sin(W*t/4.0);
    right_leg.z=STAND_HEIGH - (STAND_HEIGH-BASE_HEIGH)*sin(W*t/4.0);
    delay(50);
    t=(millis()-t0)/1000.0;
    Tam.set_legs(Tam.compute_angles(right_leg),Tam.compute_angles(left_leg));
    }
  left_leg.z=107.5;
  right_leg.z=107.5;
  //Tam.set_servo(1,0);
  //delay(750);
  //Tam.set_servo(1,90);
  Tam.get_battery_level();
  printf("\nVoltage: %0.2f\n",Tam.get_battery_level()); 
  delay(750);

  delay(750);
  Tam.set_eyes_colour(OFF);
  Tam.disable_motors();
}
*/

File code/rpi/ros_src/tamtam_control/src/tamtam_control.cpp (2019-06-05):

/**************************************************************
 *                        tamtam_control                          
 **************************************************************
 * @author FioPio (Ferriol Pey Comas)  @version v3.2 07/06/2019
 **************************************************************
 * This file provides the code for the ros node tamtam_control  
 * and it controls the tamtam movement and logic.    
 *************************************************************/


#include <tamtam.h>
#include <ros/ros.h>
#include <orientation/Orientation.h>
#include <fstream>
#include <stdio.h>
#include <math.h>

#define T_SAMPLE                     20000
#define FILENAME "/home/pi/data/data_D_PID.txt"

//Walking and base parameters
#define T_WALKING                       2.0
#define STAND_HEIGH                   121.0
#define BASE_HEIGH                    107.5
#define STEP_HEIGH                     15
#define STEP_LATERAL                   35
#define STEP_FORWARD                   22.5
#define W              (2.0*PI)/T_WALKING


#define KP_a                            0.0
#define KP_p                            0.14625

#define KI_a                            0.0
#define KI_p                            1.76

#define KD_a                            0.0
#define KD_p                            0.1942
#define KD_e                            0.0
 
#define MAX_PITCH_CORRECTION           40.0
#define MAX_ALPHA_CORRECTION           20.0
#define PITCH_0                       -85.1875

#define T_CORRECCIO                    50 //ms -> 20Hz
#define FILTRE_DERIV                    0.1

class TamTam_Control
{
public:
  TamTam_Control()
  {
    Tam.setup();
    readed=false;
    write=true;
    myfile.open (FILENAME);
    this->n = ros::NodeHandle("~");
    this->orient_sub = n.subscribe("/orientation",1, &TamTam_Control::orientation_callback, this);
    t_ant=millis();
    t_init_file=t_ant;
    step=0;
    Tam.to_home();
    left_leg.zeta=0;
    right_leg.zeta=0;
    left_leg.x=0;
    right_leg.x=0;
    left_leg.y=0;
    right_leg.y=0;
    left_leg.z=BASE_HEIGH;
    right_leg.z=BASE_HEIGH;
    correction_p=0;
    err_p_f_a=0;
    step=0;
    t=0;
  }

  void orientation_callback(const orientation::Orientation orient_msg)
  {
    yaw=orient_msg.yaw;
    roll=orient_msg.roll;
    pitch=orient_msg.pitch;
    readed=true;
  }
  
  ////////////////////////////////////////////////////////////
  void loop()
  {
    switch(step)
    {
       case 3:
	 if(t>3)
	 {
	   t=0;
	   step=0;
	 }
	 break;
       case  0:
	 right_leg.y= STEP_LATERAL * sin(W*t);
	 left_leg.y= STEP_LATERAL * sin(W*t);
	 if(t > T_WALKING/4.0 )
	 {
	     t  = 0;
	     right_leg.y = STEP_LATERAL ;
	     left_leg.y = STEP_LATERAL ;
	     step++;
	 }
  	 break;
    }
    
    if(millis()-t_ant > T_CORRECCIO)
    {
      float y_pitch=pitch-PITCH_0;
      float dt=(millis()-t_ant)/1000.0;
      t_ant=millis();
      err_p= - y_pitch;
      float err_p_f=FILTRE_DERIV*err_p +(1-FILTRE_DERIV) * err_p_f_a;
      err_p_f_a=err_p_f;
      de_p= (err_p_f) - err_ant_p ;
      err_ant_p=err_p_f;
      err_acu_p+=err_p * dt;
    
      correction_p=-KP_p* y_pitch + KD_p * (de_p /dt) + KI_p * err_acu_p;
      if(correction_p > MAX_PITCH_CORRECTION)
	{
	  correction_p = MAX_PITCH_CORRECTION;
	  err_acu_p-=err_p*dt;
	}
      if(correction_p < -MAX_PITCH_CORRECTION)
	{
	  correction_p = -MAX_PITCH_CORRECTION;
	  err_acu_p-=err_p*dt;
	}
      
      if((millis()-t_init_file)>T_SAMPLE && write)
      {
	write=false;
	myfile.close();
	ROS_INFO("DADES ESCRITES");
	Tam.set_eyes_colour(OFF);
	Tam.disable_motors();
      }
      else
      {
	if(write && readed)
        {
	    readed=false;
	    myfile << pitch-PITCH_0 <<" ; "<<millis()-t_init_file<<";"<< correction_p<<"\n";
       }
     }
     if(write)
     {
      //computig the angles to get the desired position
      left_cfg=Tam.compute_angles(left_leg);
      right_cfg=Tam.compute_angles(right_leg);
      //aplaying the corrections for the PID stabilizing
      // right_cfg.epsilon+=(correction_epsilon_r/180.0)*PI;
      //left_cfg.epsilon+=correction_epsilon_l;
      right_cfg.delta+=(correction_p/180.0)*PI; 
      left_cfg.delta+=(correction_p/180.0)*PI;
      right_cfg.gamma-=(correction_p/(180.0*2))*PI;
      left_cfg.gamma-=(correction_p/(180.0*2))*PI;
      right_cfg.beta+=(correction_p/(180.0*8))*PI;
      left_cfg.beta+=(correction_p/(180.0*8))*PI;
      //right_cfg.alpha+=correction_alpha_r;
      //left_cfg.alpha+=correction_alpha_l;
      //Seting the servomotors*/
      Tam.set_legs(right_cfg,left_cfg);
    }
     t+=(millis()-t_ant_c)/1000.0;
     t_ant_c=millis();
    }
  }
  //////////////////////////////////////////////////////////////////////  

private:
  float yaw, roll, pitch;
  ros::NodeHandle n;
  ros::Subscriber orient_sub;
  tamtam Tam;
  bool readed,write;
  std::ofstream myfile;
  unsigned int t_ant, t_init_file, t_ant_c;
  float t;
  char step;
  LEG_SETPOINT_T left_leg,right_leg;
  LEG_CONFIGURATION_T left_cfg, right_cfg;
  float correction_p;
  float de_p, err_p, err_ant_p, err_acu_p;
  float err_p_f_a;
};


int main(int argc, char **argv)
{
  ros::init(argc, argv, "tamtam_control");
 TamTam_Control ttc;
  ROS_INFO("node starts");
  while (ros::ok())
    {
      ttc.loop();
      ros::spinOnce();
    }
  return 0;
}

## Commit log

2018-12-03 created the mg90s servo model
    [materials.ods, mg90s.scad]
2018-12-04 Added the first piece, two_servo_holder, and the STL. Small modifies added to the mg90s and materials files.
    [materials.ods, mg90s.scad, two_servo_holder.scad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]
2018-12-04 small fixes
    [materials.ods, mg90s.scad, two_servo_holder.scad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]
2018-12-04 deleted unusefull statement
    [mg90s.scad]
2018-12-04 fixed hole missing
    [two_servo_holder.scad, two_servo_holder.stl]
2018-12-04 added axis continuation
    [mg90s.scad]
2018-12-04 added right foot
    [materials.ods, right_foot.scad, right_foot.stl]
2018-12-05 added the lower part of the leg
    [lower_leg_right.scad, lower_leg_right.stl, materials.ods]
2018-12-05 updated pieces
    [lower_leg_right.scad, lower_leg_right.stl]
2018-12-05 first servo aproximation
    [materials.ods]
2018-12-05 added upper part of the right leg
    [materials.ods, upper_leg_right.scad, upper_leg_right.stl]
2018-12-05 new size for the foot
    [right_foot.scad, right_foot.stl]
2018-12-06 added description
    [upper_leg_right.scad]
2018-12-06 added right leg bracket
    [materials.ods, right_leg_bracket.scad, right_leg_bracket.stl]
2018-12-06 updated the right leg bracket
    [right_leg_bracket.scad, right_leg_bracket.stl]
2018-12-07 added the new version of body servos holder
    [materials.ods, servo_body_holder.scad, servo_body_holder.stl]
2018-12-07 format fixing
    [servo_body_holder.scad]
2018-12-07 added the board files but not finished
    [materials.ods, tamtam_board.kicad_pcb, tamtam_board.sch]
2018-12-07 added some pieces
    [body_back_cover.scad, body_data.scad, body_front_cover.scad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]
2018-12-07 updated the body covers
    [Letters.dxf, body_front_cover.scad, body_front_cover.stl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]
2018-12-07 little more done
    [tamtam_board.sch]
2018-12-09 some more work done
    [tamtam_board.sch]
2018-12-09 piece updated
    [body_front_cover.stl, lower_leg_right.stl, mg90s.scad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]
2018-12-09 schematic finished
    [tamtam_board.sch]
2018-12-09 first board placement design
2018-12-11 board finished
    [tamtam_board-B.Cu.gbr, tamtam_board-B.Mask.gbr, tamtam_board-B.Paste.gbr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]
2018-12-11 new update
    [body_back_cover.stl, body_back_cover_extra.scad, body_back_cover_extra.stl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]
2018-12-11 some component updates
    [materials.ods]
2018-12-14 new head started
    [head_lower_part.scad]
2018-12-14 head V2
    [head_lower_part.scad, head_upper_part.scad]
2018-12-14 finished arms and head
    [arm_lower_part.scad, arm_lower_part.stl, arm_upper_part.scad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]
2018-12-21 Some last steps before asembling
    [head_lower_part.scad, head_upper_part.scad, materials.ods]
2019-01-19 A little size difference between the model servo and the real servo makes me to redesign some parts
    [arm_lower_part.stl, arm_upper_part.stl, body_back_cover_extra.stl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]
2019-01-19 a simple code in Arduino and a library to do it easy to program
2019-01-19 added an exlanation about how the invere kinematics have been computed
2019-01-19 inverse kinematics
2019-01-20 some head sizes fixed
    [head_lower_part.scad, head_lower_part.stl]
2019-01-20 fixed the foot
    [right_foot.scad, right_foot.stl]
2019-01-20 some format changed
    [mg90s.scad]
2019-01-20 definitive foot design
    [right_foot.scad]
2019-04-14 updated the two_servo_holder
    [two_servo_holder.scad, two_servo_holder.stl]
2019-04-17 head last version
    [head_upper_part.scad]
2019-04-17 last version two servo holders
    [two_servo_holder.scad, two_servo_holder.stl]
2019-04-18 updated lower leg right
    [lower_leg_right.scad, lower_leg_right.stl]
2019-04-22 Last version of TamTam
    [arm_lower_part.scad, arm_lower_part.stl, arm_upper_part.scad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]
2019-05-15 back cover modifyed to get more room
    [body_back_cover.scad, body_back_cover.stl]
2019-05-31 pitch stability control implemented and working
    [tamtam.h, tamtam_control.cpp]
2019-06-05 last hardware version, starting deeply software
    [arm_lower_part.scad, arm_upper_part.scad, body_back_cover.scad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]
